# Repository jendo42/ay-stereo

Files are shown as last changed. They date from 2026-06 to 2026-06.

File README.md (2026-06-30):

# ZX Spectrum AY Stereo
This is *yet another* but opensource design of the ACB/ABC stereo enhancement for ZX Spectrum computers. Original electrical design by Ben Versteeg / [ByteDelight.com](https://www.bytedelight.com).

There are multiple variants of the wiring in the [docs](docs/) directory but the original installation manual from ByteDelight v2014 can be found [here](docs/bd-v2014-manual.pdf).

Added option to solder the additional resistors for +2/+3 models directly on board.

## Latest version
 - gerber data generated for JLCPCB are [here](r1/gerber/)
 - schematic for *r1* is [here](r1/ay-stereo-sch.pdf)

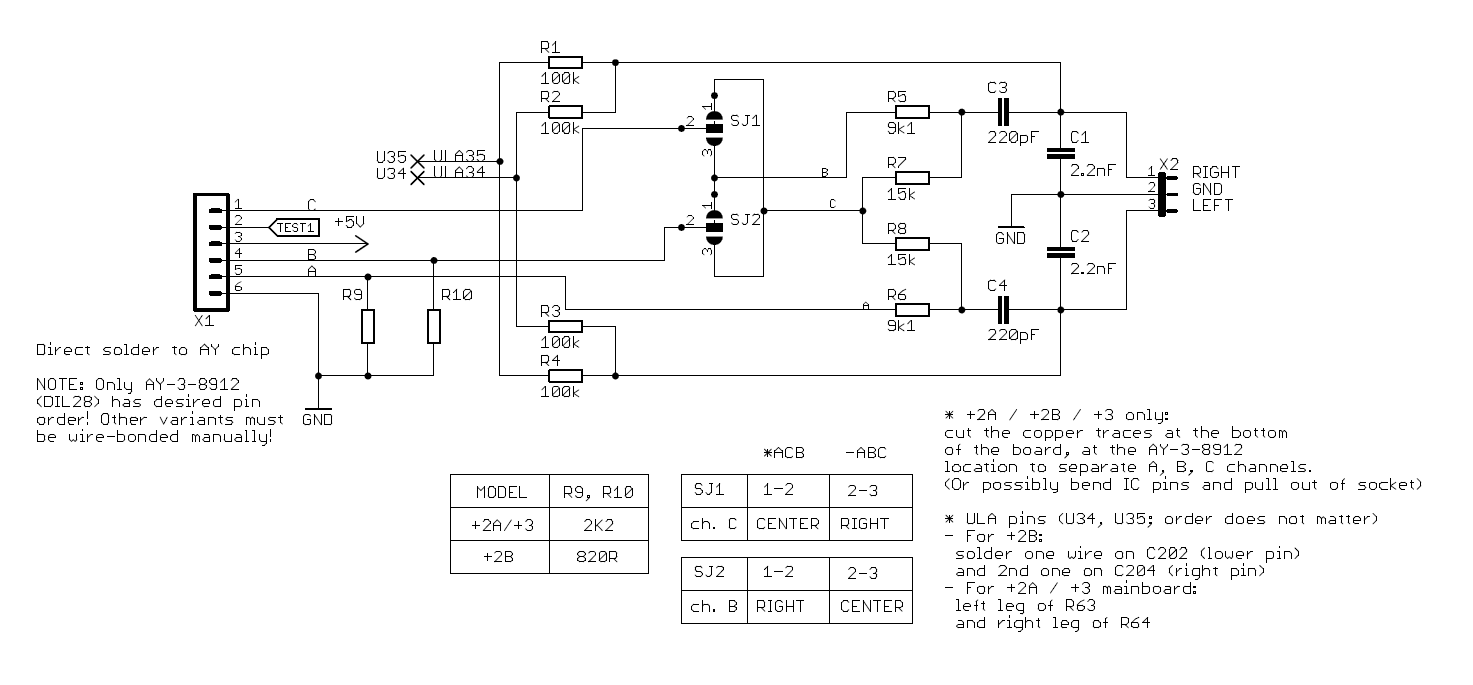
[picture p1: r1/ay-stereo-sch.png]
Schematic of ay-stereo r1

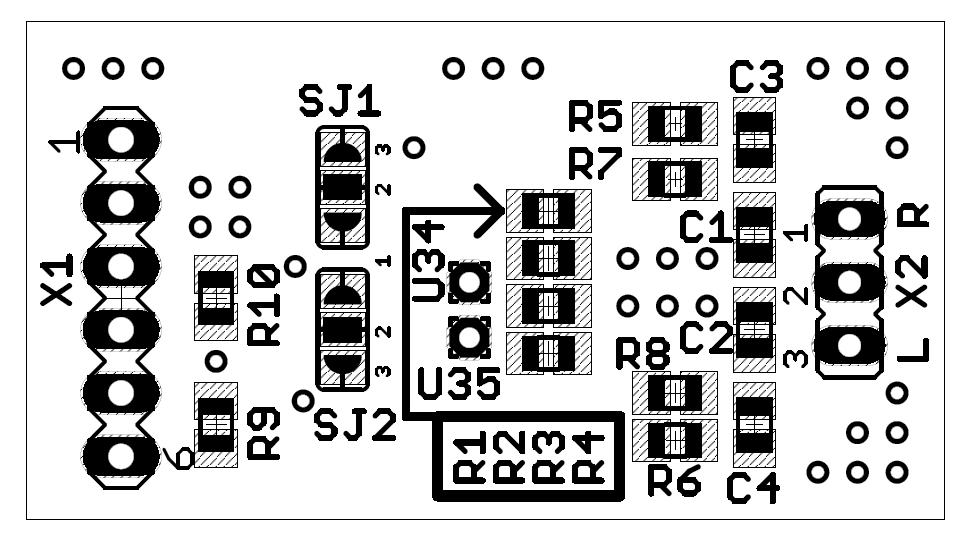
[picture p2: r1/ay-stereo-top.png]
Top view of ay-stereo r1 PCB


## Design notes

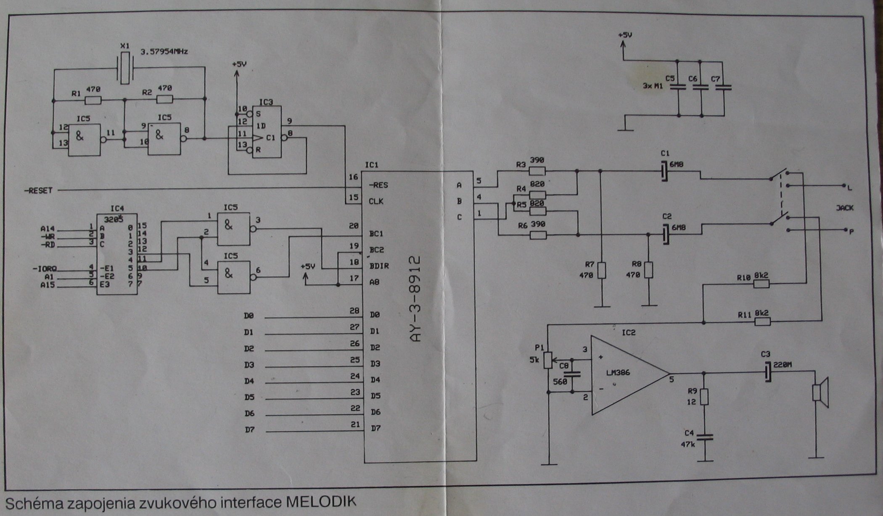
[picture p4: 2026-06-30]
docs/melodik-sch.jpg

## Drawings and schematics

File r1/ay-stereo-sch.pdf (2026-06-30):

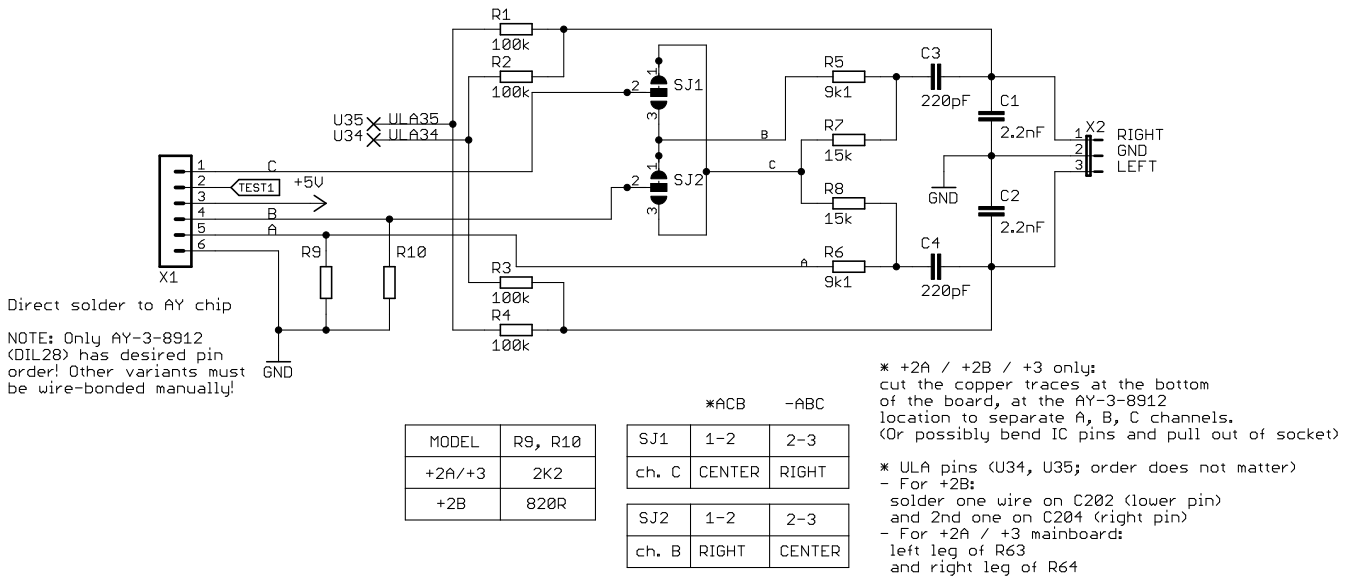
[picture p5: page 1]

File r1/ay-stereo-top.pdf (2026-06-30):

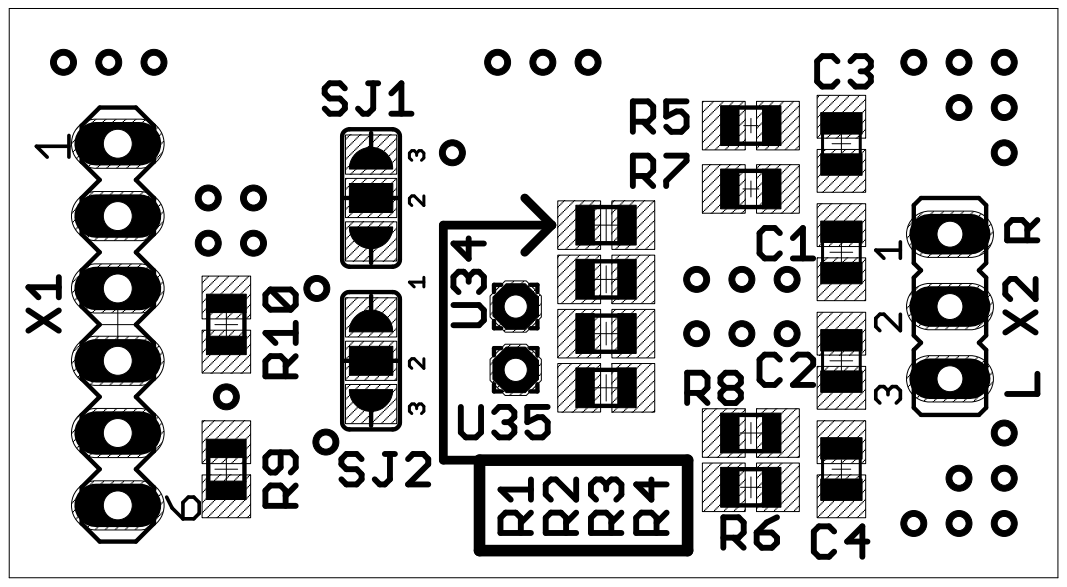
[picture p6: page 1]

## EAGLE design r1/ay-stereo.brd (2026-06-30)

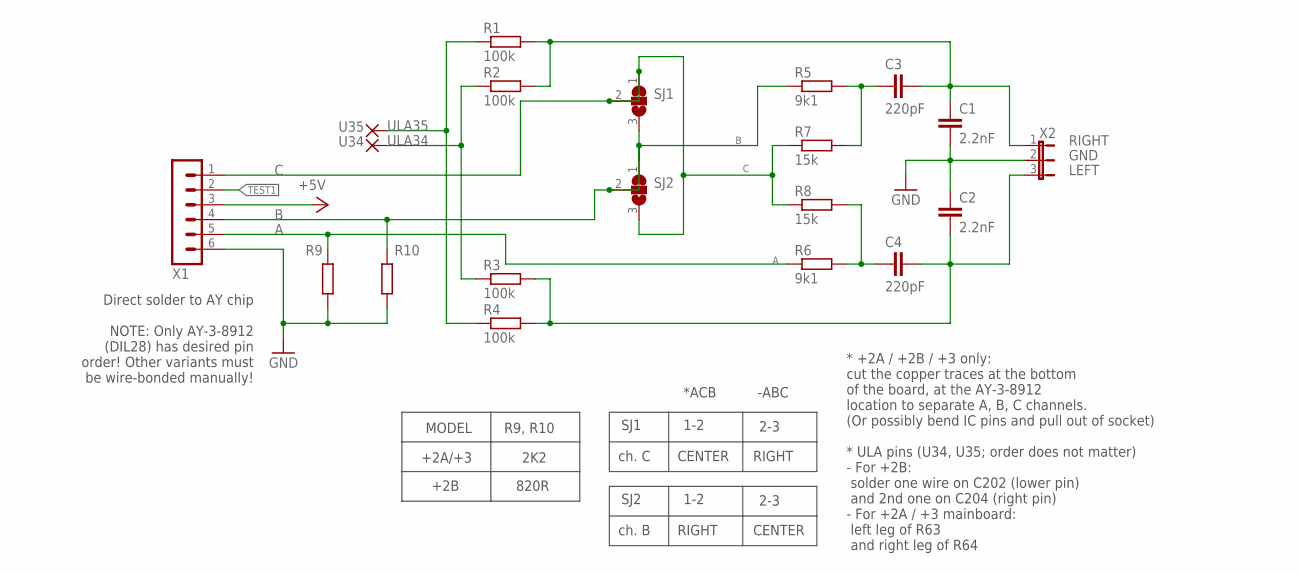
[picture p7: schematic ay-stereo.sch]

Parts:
C1, C2: 2.2nF; C0805
C3, C4: 220pF; C0805
R1, R2, R3, R4: 100k; R0805
R5, R6: 9k1; R0805
R7, R8: 15k; R0805
R9, R10: R-EU_R0805; R0805
SJ1, SJ2: SJ2W; SJ_2
U34, U35: 1,6/0,8
X1: MA06-1
X2: JP2E; JP2

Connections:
+5V: X1.3
A: R6.1, R9.2, X1.5
B: R5.1, R10.2, SJ1.3, SJ2.1, SJ2.2, X1.4
C: R7.1, R8.1, SJ1.1, SJ1.2, SJ2.3, X1.1
GND: C1.2, C2.1, R9.1, R10.1, X1.6, X2.2
LEFT: C2.2, C4.2, R3.2, R4.2, X2.3
unnamed: C3.1, R5.2, R7.2
unnamed: C4.1, R6.2, R8.2
RIGHT: C1.1, C3.2, R1.2, R2.2, X2.1
TEST1: X1.2
ULA34: R2.1, R3.1, U34.1
ULA35: R1.1, R4.1, U35.1

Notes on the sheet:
SJ1
1-2
2-3
ch. C
CENTER
RIGHT
SJ2
ch. B
+2B
+2A/+3
R9, R10
820R
2K2
MODEL
* +2A / +2B / +3 only: cut the copper traces at the bottom of the board, at the AY-3-8912 location to separate A, B, C channels. (Or possibly bend IC pins and pull out of socket) * ULA pins (U34, U35; order does not matter) - For +2B: solder one wire on C202 (lower pin) and 2nd one on C204 (right p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
*ACB
-ABC
Direct solder to AY chip NOTE: Only AY-3-8912 (DIL28) has desired pin order! Other variants must be wire-bonded manually!

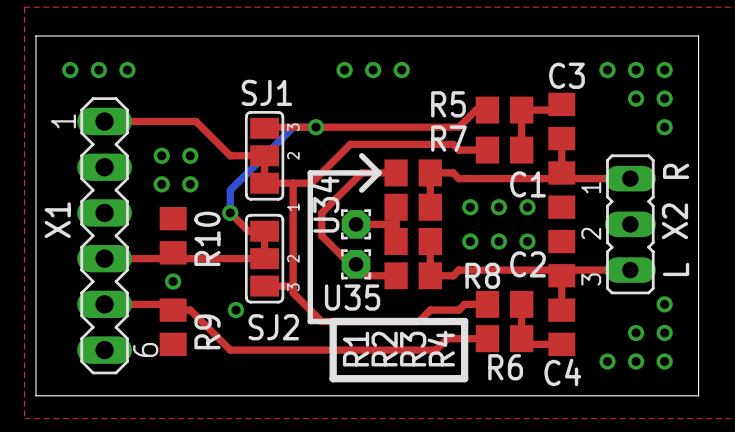
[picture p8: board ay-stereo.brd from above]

Board: 2 copper layers, 36.8 x 20.0 mm, 20 parts (0 on the bottom side), 10 nets.

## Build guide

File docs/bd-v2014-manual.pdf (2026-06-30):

# Stereo audio enhancement for the ZX Spectrum 128K / +2 / +2A / +2B / +3

## Overview

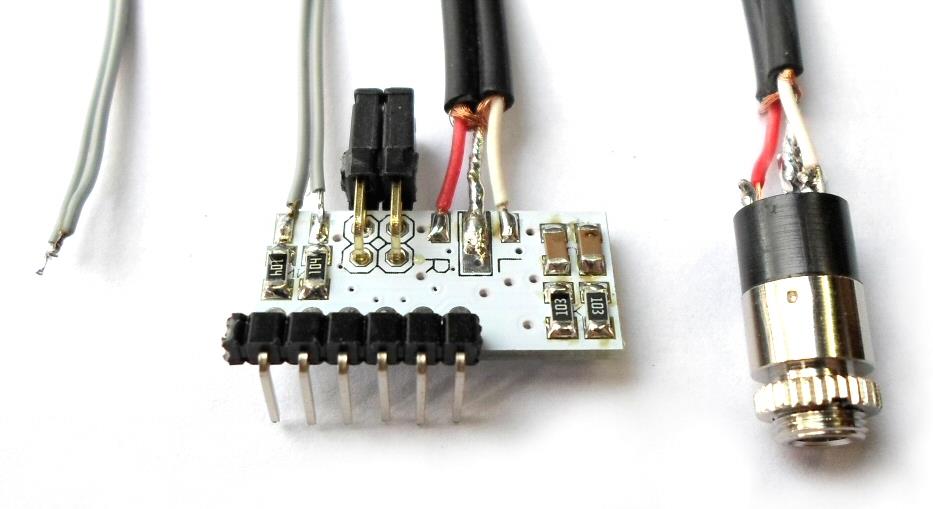
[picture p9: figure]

This stereo audio enhancement gives your ZX Spectrum 128K:
1. Crips and clear stereo sound from the AY-3-8912 sound generator
2. Beeper sound on both left and right output channels
3. Load and save sounds on both channels
4. And finally you will hear all sound at equal volume levels!

The stereo enhancement is compatible with all 128K ZX Spectrum models:
128K+ (toastrack model), +2 (grey), +2A, +2B, +3 and clones with AY-3-8912 sound chip.

## Assembling complexity

You will need some soldering skills to assemble the kit.
I’m not responsible for any defects or damage caused by building the stereo enhancement into your ZX Spectrum!

## Assembling the board is at your own risk!

The sold kits are pre-assembled carefully, but there may always be a bad solder connection or short-circuit; please check the board yourself again before assembling!

## ABC / ACB channel mixing

Channel mixing means how the three AY-3-8912 output channels (A, B and C) are mixed to the two stereo output channels (left and right). This means that if you want to hear a song as it was arranged, you should select the correct channel mixing.

There are two common mixing standards:
ABC: A is mixed to right, B to left and right, and C to left (common in west-Europe).
ACB: A is mixed to right, C to left and right, and B to left (common in east-Europe). There are two jumpers to select ABC or ACB mixing:

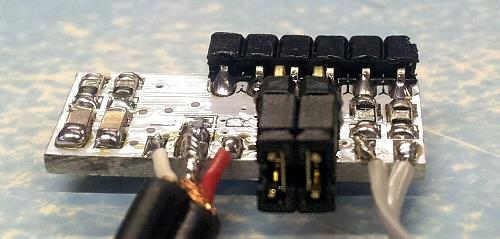
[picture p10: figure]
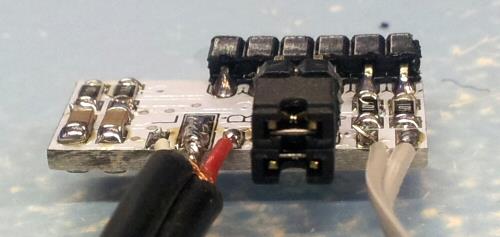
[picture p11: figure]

ABC channel mixing (west-Europe) | ACB channel mixing (east-Europe)

## Assembling instructions

The photos in these instructions are from various ZX Spectrum models.

1. Open your ZX Spectrum: | 2. Carefully disconnect the keyboard: +2/+2A/+2B: disconnect taperecorder cable
3. Locate the AY chip: | 4. Pre-solder the pins 1, 4, 5 and 6: notch pin 1 Pin 1 is first pin anti-clockwise from notch
5. +2A / +2B / +3 only:
Amstrad decided to shortcircuit the AY-3-8912 output channels on +2A, +2B and +3 for mono output.

We want to have the channels seperated.

So, cut the cupper lines at the bottom of the +2A / +2B / +3 board (at the AY-3-8912 location), at the locations shown on the picture on the right.

How to determine the difference between +2A and +2B?
You may need this info in paragraphs 7 and 8. Often +2B boards are assembled in a +2A case, so you need to know what board you are using.
+2A mainboard: | +2B mainboard:

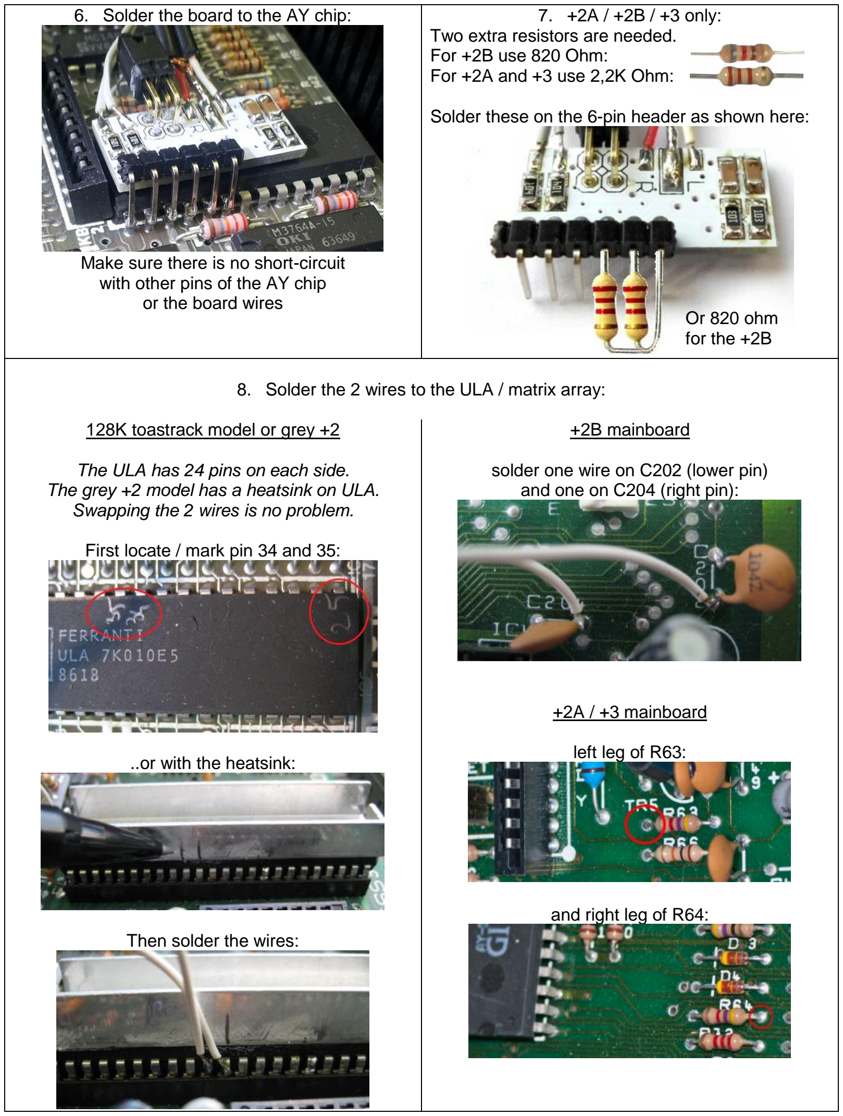
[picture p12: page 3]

6. Solder the board to the AY chip:

Make sure there is no short-circuit with other pins of the AY chip or the board wires

7. +2A / +2B / +3 only:
Two extra resistors are needed.
For +2B use 820 Ohm:
For +2A and +3 use 2,2K Ohm:

Solder these on the 6-pin header as shown here:

8. Solder the 2 wires to the ULA / matrix array:

128K toastrack model or grey +2

The ULA has 24 pins on each side. The grey +2 model has a heatsink on ULA. Swapping the 2 wires is no problem.

First locate / mark pin 34 and 35:

..or with the heatsink:

Then solder the wires:

+2B mainboard

solder one wire on C202 (lower pin) and one on C204 (right pin):

+2A / +3 mainboard

left leg of R63:

and right leg of R64:

Or 820 ohm
for the +2B

9. Fitting the stereo audio socket:
a. Find a good location
b. Drill a 5 mm hole
c. Insert the socket
d .Fit the ring

Please take your time for finding a good location; it’s easy to make a mistake here!

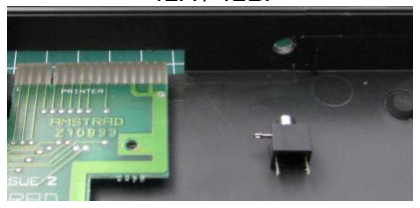
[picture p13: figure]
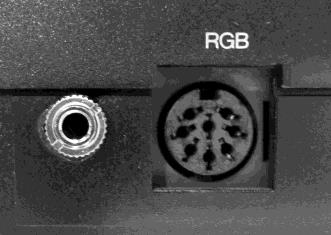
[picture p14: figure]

Toastrack: | Grey +2: | +2A / +2B:

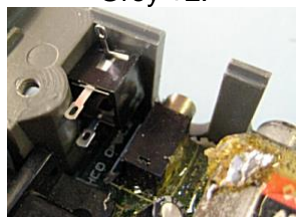
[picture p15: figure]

10. Finally:
a. Connect all cables of your ZX Spectrum
b. Test the output (see test routine)
c. Close your ZX Spectrum

## Testing

This BASIC code plays a note on channel A first, then B, then C, and performs a BEEP.
Use it to test if all channels are mapped to the correct output (left, right or center).

10 PLAY "A"
20 PLAY "", "A"
30 PLAY "", "", "A"
40 BEEP 1,10
50 GOTO 10

## Board layout and schematic

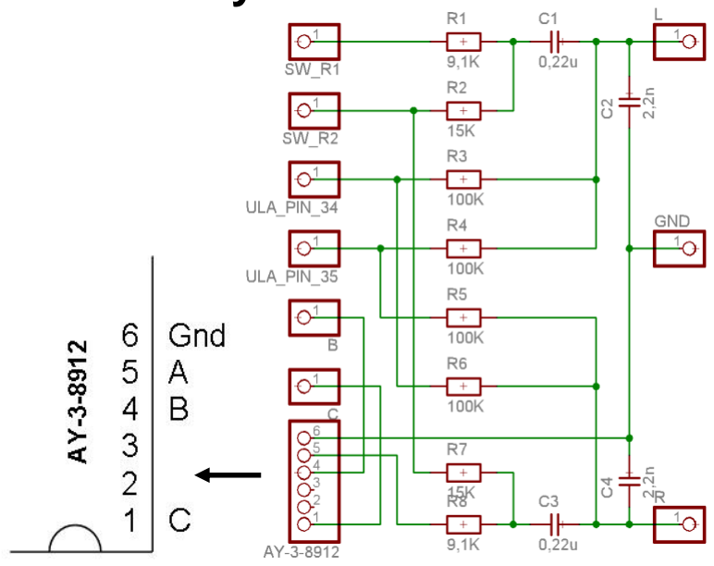
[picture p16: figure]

Document version: v2.2 / March 2015 © 2014 Ben Versteeg
